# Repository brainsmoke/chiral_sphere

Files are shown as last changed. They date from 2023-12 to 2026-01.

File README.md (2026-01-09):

# Chiral Sphere

LED lamp based on a chiral spherical tiling consisting of 20 triangles and
12 Pentagons where the edge-length ratio triangle:pentagon is 2:1.

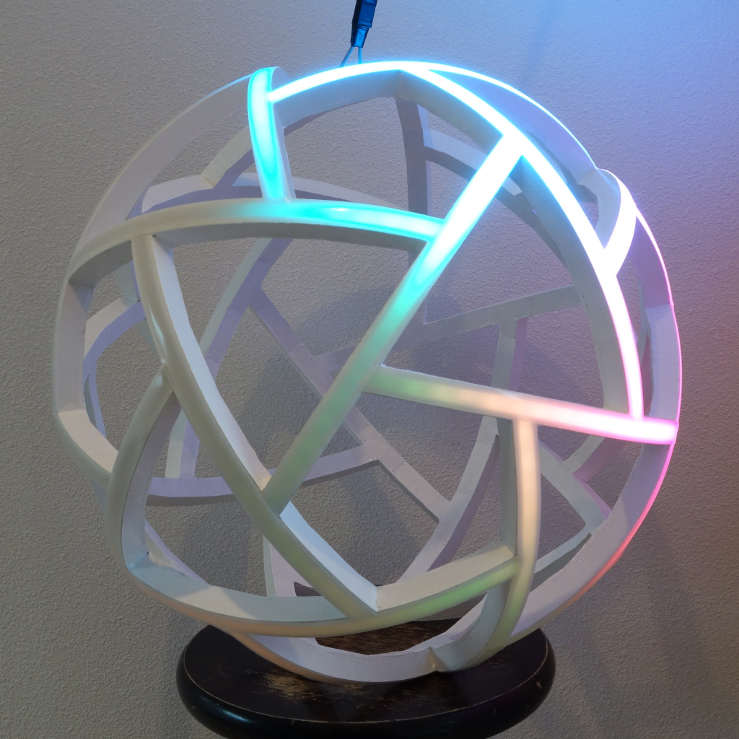
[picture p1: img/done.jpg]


[Video](https://mastodon.social/@brainsmoke/111589632039788005)

# Materials

* 2x 5m WS2812 LED strips, 60 LEDs/m spacing, 10mm wide, cut into 30 strips of 17
* +/- 11 meters flexible diffuser, 12mm wide
* [custom joint PCBs [kicad]](pcb/yjoint) [[svg]](pcb/yjoint/penta_joint.svg), [untested flexpcb alternative [kicad]](pcb/yjoint_v2) [[svg]](pcb/yjoint_v2/penta_joint_v2.svg)
* [LED driver board](https://github.com/brainsmoke/leddriver3d/tree/main/pcb/driver_slim_v1), [LED driver board v2](https://github.com/brainsmoke/leddriver3d/tree/main/pcb/driver_slim_v2)
* thin wire (for connecting the data lines)
* 2x ~30cm thick wire (to handle high currents near the power connector)
* 3mm plywood, 4x 600x400mm
* white paint
* wood glue

# Maths

* [Formula for the relation between corner arc and edge-length for regular N-gons on the unit sphere](https://github.com/brainsmoke/geometry/blob/main/spherical/ngonmath.png)
* [Calculation of the corner arc for this spherical tiling](https://github.com/brainsmoke/geometry/blob/main/spherical/2tri1penta.scad#L8-L34)
* [LED Locations & normals](https://github.com/brainsmoke/geometry/blob/main/scripts/led_locations.py)

# Cutting

Based on output from [one of my scripts](https://github.com/brainsmoke/geometry/blob/main/scripts/tube.py), but
with the outer panels removed so that the tubes become U-profiles and the sides modified so that they trace
a perfect sphere.

[Laser cut shapes](cut/v1/led.svg) (with some spares; apply appropriate kerf width compensation before cutting)

# Wiring

All strips are positioned such that data-in is above data-out, with one pentagon chosen
as top.  The strips are connected as five point-symmetrical led strips with 102 LEDs each
according to [this OpenSCAD model](doc/wiring.scad).

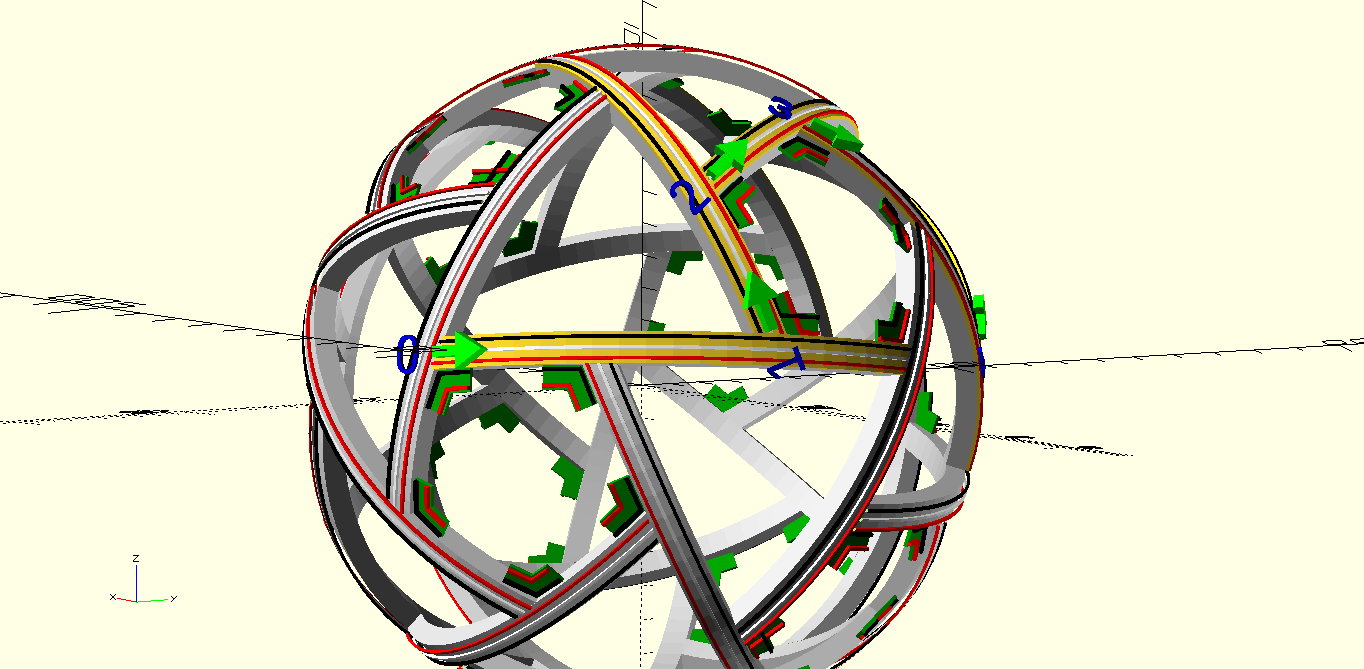
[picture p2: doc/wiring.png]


# LED Driver

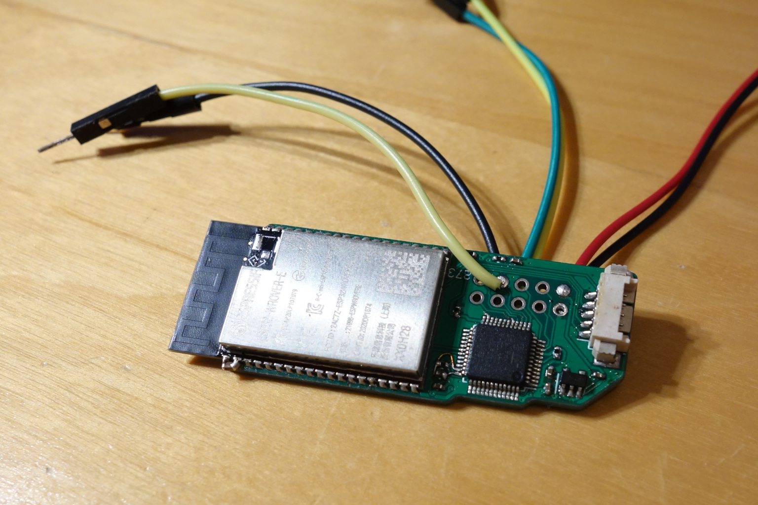
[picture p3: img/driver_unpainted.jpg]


[PCB](https://github.com/brainsmoke/leddriver3d/tree/main/pcb/driver_slim_v1)

# Software

* [Driver software repo](https://github.com/brainsmoke/leddriver3d)
* [STM32 Firmware: strip5.bin](https://github.com/brainsmoke/leddriver3d/tree/main/firmware/stm32/strip5)
* [LED positions](https://github.com/brainsmoke/leddriver3d/blob/main/firmware/esp32/models/chiral_tiling/leds.json)
* [conf/hardware.json](https://github.com/brainsmoke/leddriver3d/blob/main/firmware/esp32/conf/chiral_tiling/hardware.json)

# More pictures

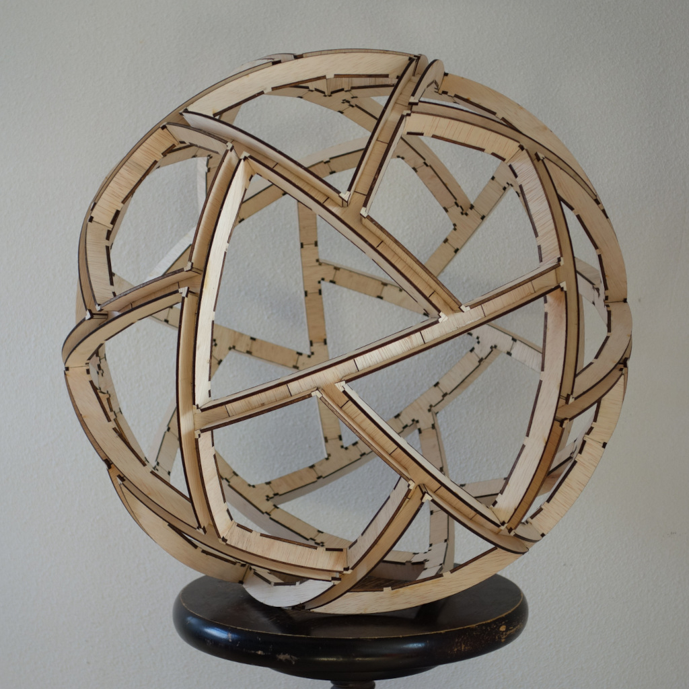
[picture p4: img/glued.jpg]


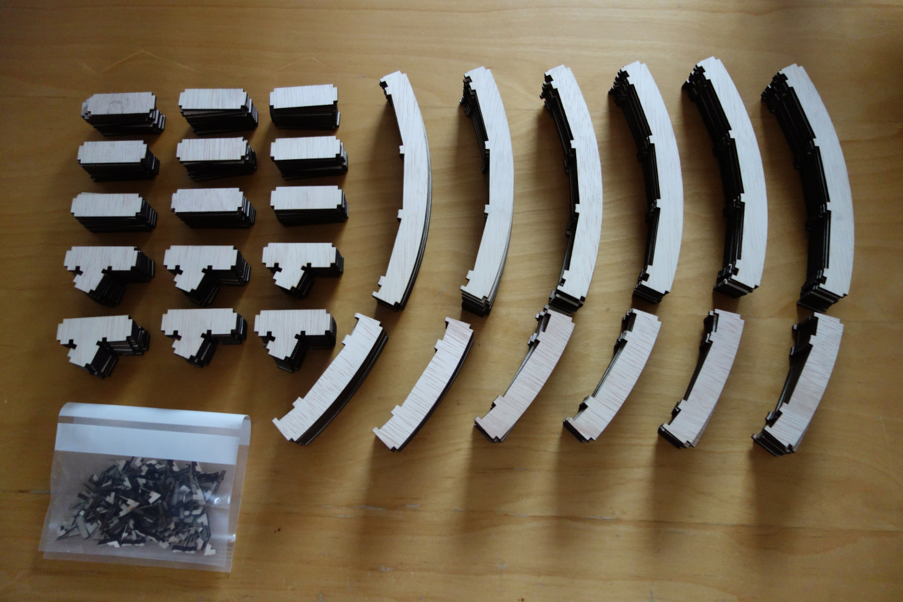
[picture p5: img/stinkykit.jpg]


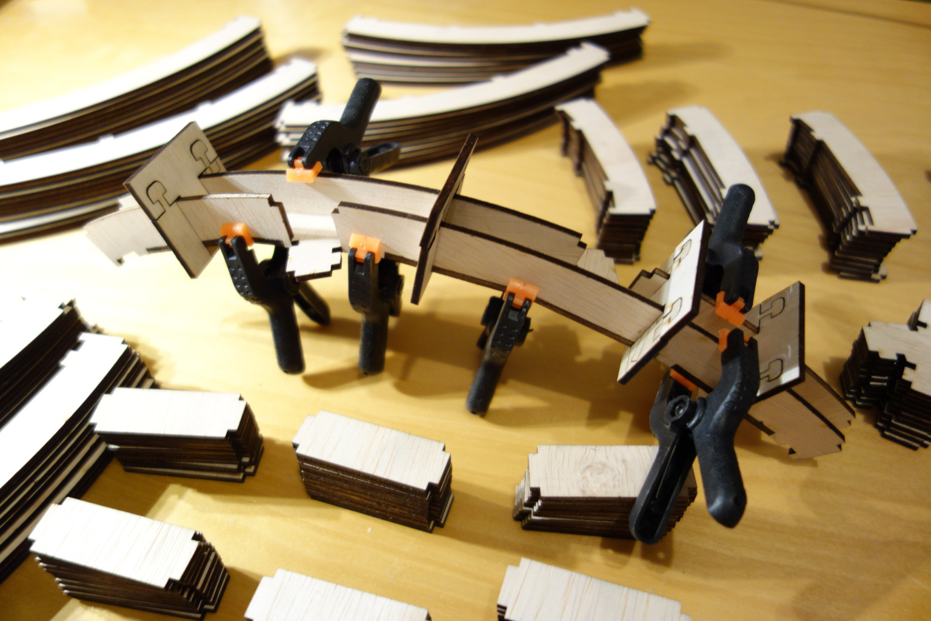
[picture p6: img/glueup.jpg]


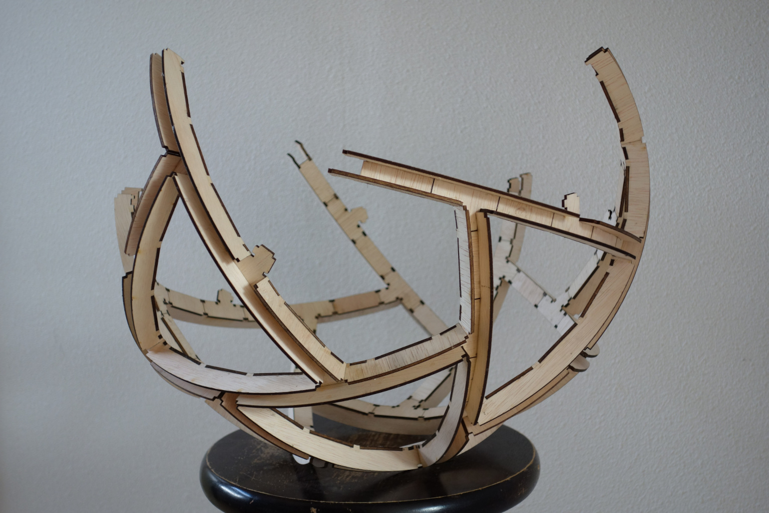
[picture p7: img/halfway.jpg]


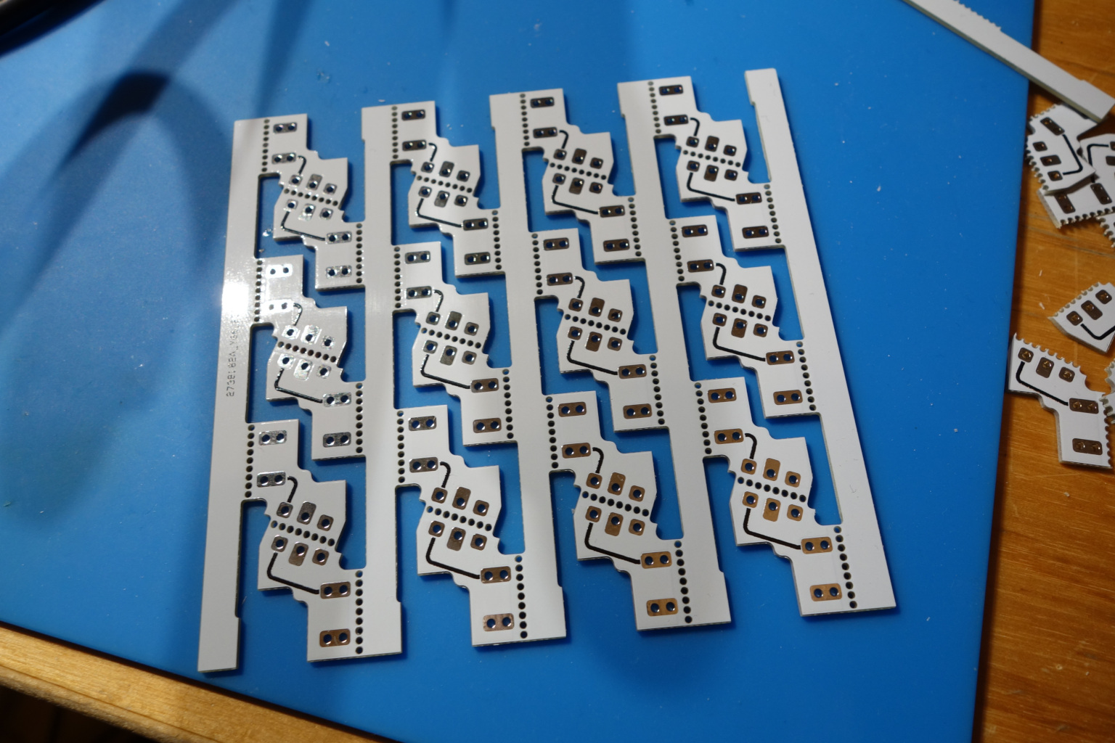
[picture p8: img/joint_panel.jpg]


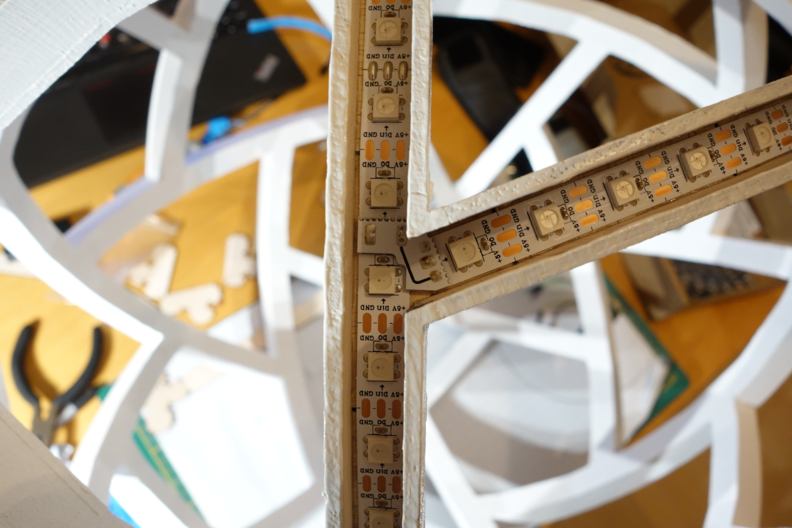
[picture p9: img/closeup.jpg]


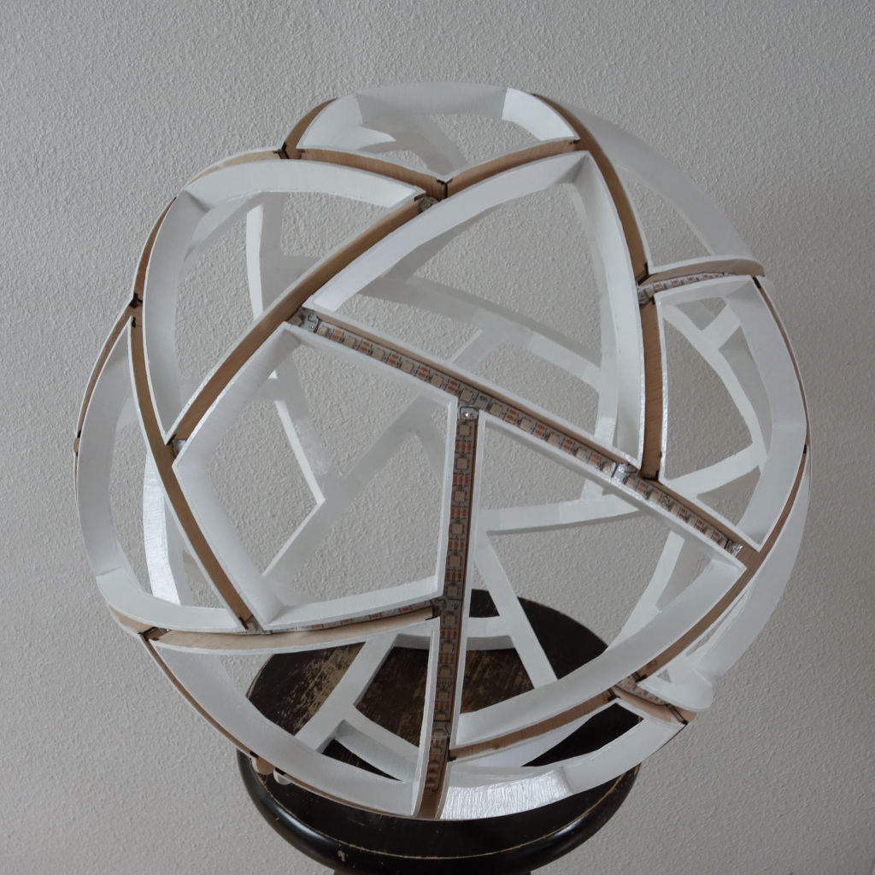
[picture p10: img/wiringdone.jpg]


Add extra capacity to the strip which needs to handle the most Amps.
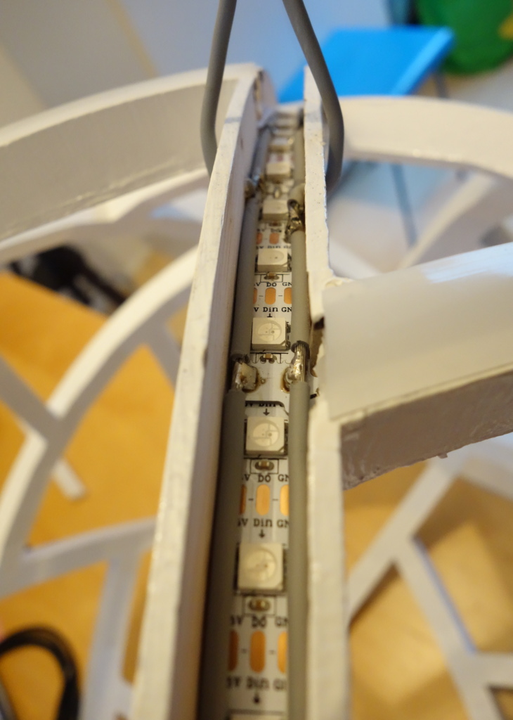
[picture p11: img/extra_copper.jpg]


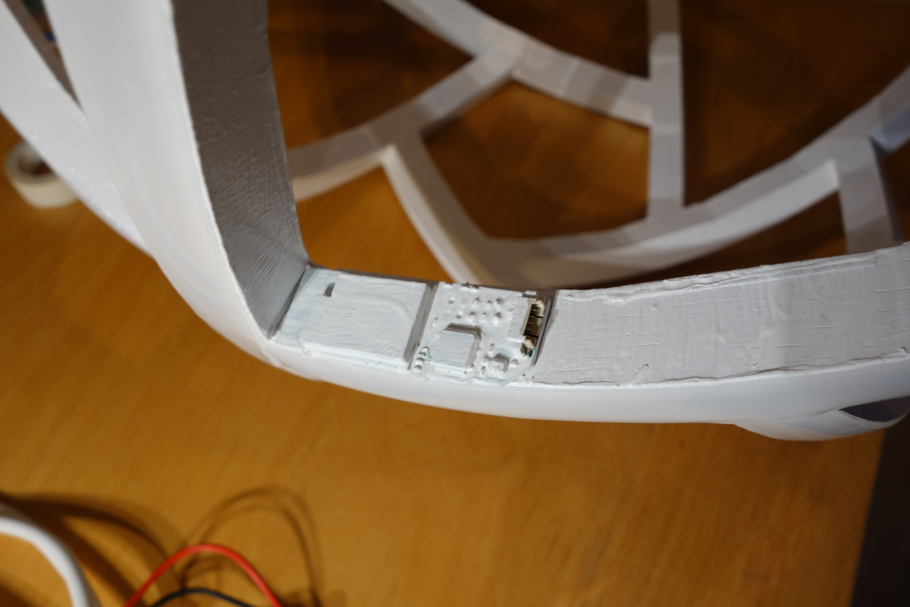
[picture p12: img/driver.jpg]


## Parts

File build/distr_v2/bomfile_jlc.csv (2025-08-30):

Comment | Designator | Footprint | JLCPCB Part #
1uF | C1,C2,C3,C4,C5 | Capacitor_SMD:C_0603_1608Metric | C15849
BSMD1812-200-30V | F1 | Fuse:Fuse_1812_4532Metric | C960026
0Ohm,0ohm | R1,R4 | Resistor_SMD:R_0603_1608Metric | C21189
330R | R2,R3,R5 | Resistor_SMD:R_0603_1608Metric | C23138
STM32F030F4Px | U2 | Package_SO:TSSOP-20_4.4x6.5mm_P0.65mm | C89040
AP2112K-3.3 | U3 | Package_TO_SOT_SMD:SOT-23-5 | C51118
74LVC2G17 | U4 | Package_TO_SOT_SMD:SOT-23-6_Handsoldering | C10429
TLP2361 | U5 | Package_SO:SO-5_4.4x3.6mm_P1.27mm | C107626

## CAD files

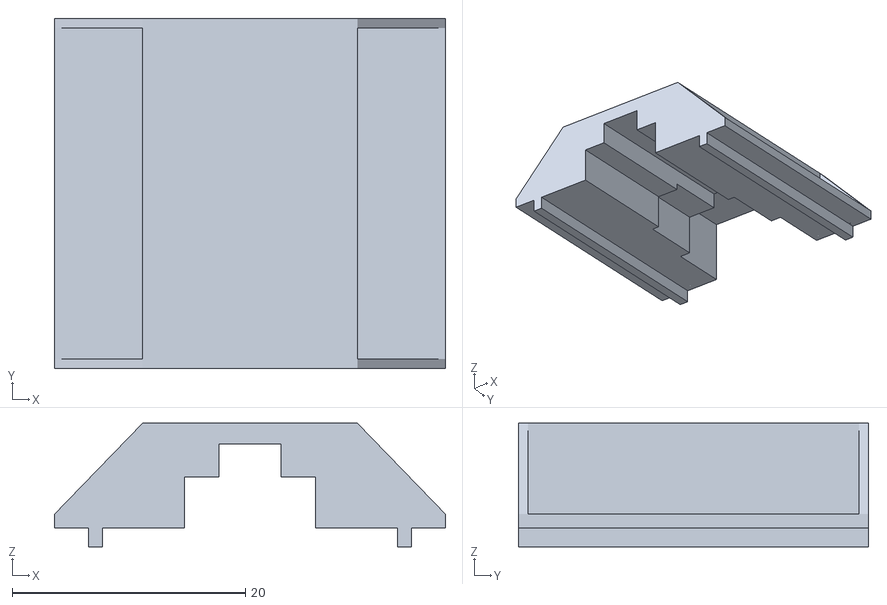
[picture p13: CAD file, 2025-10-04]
scad/assembly_tool.stl
33.5 x 30.0 x 10.6

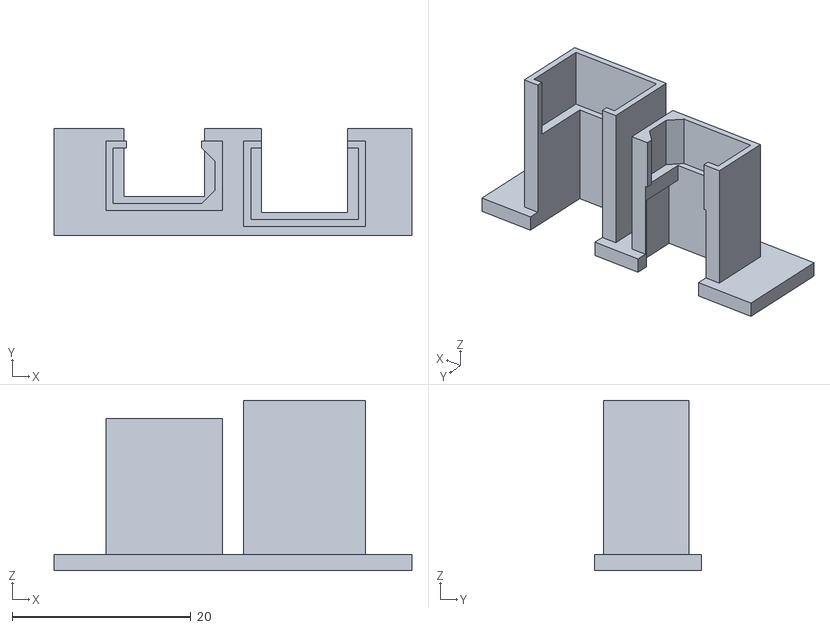
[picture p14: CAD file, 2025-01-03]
scad/assembly_tool_big.stl
40.0 x 12.0 x 19.0

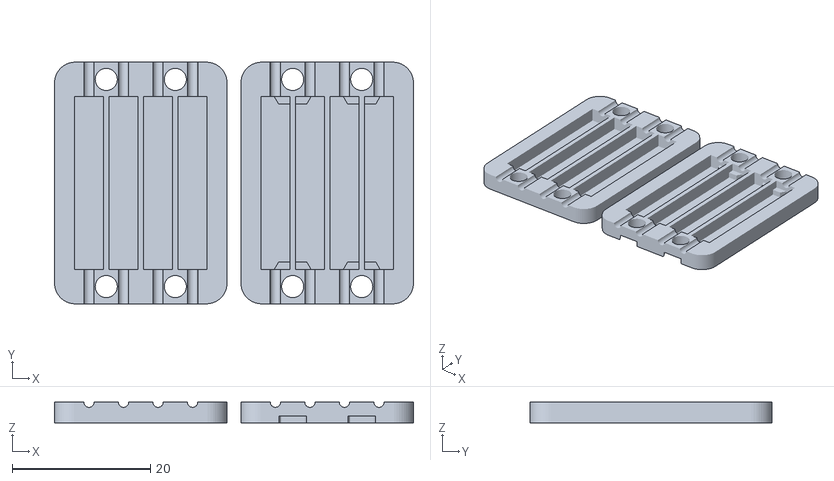
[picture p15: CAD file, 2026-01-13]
scad/clamp.stl
52.0 x 35.0 x 3.00

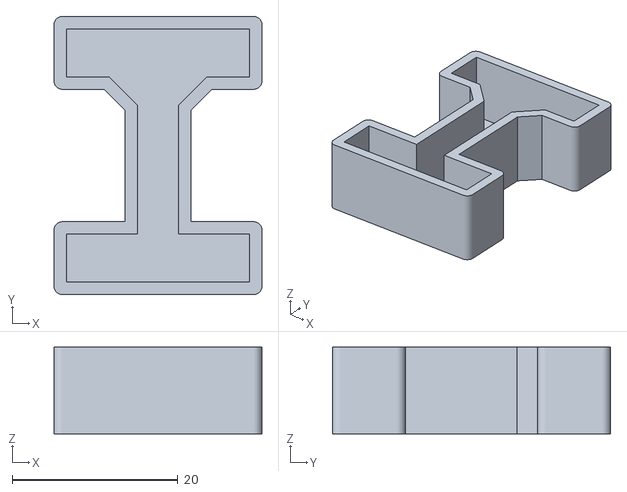
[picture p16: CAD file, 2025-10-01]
scad/power_insert.stl
25.1 x 33.6 x 10.5

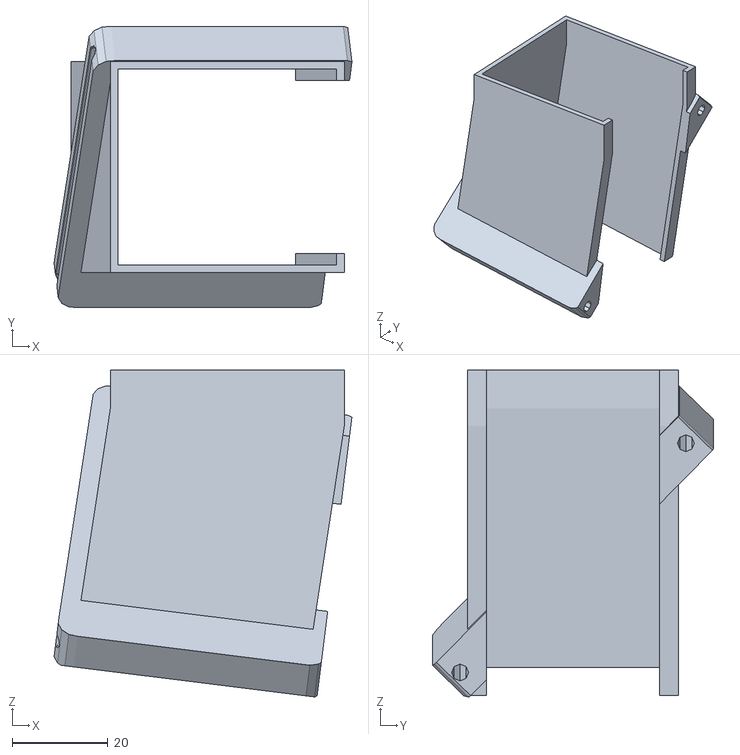
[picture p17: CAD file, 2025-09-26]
scad/wire_guide_big.stl
62.2 x 58.7 x 68.2

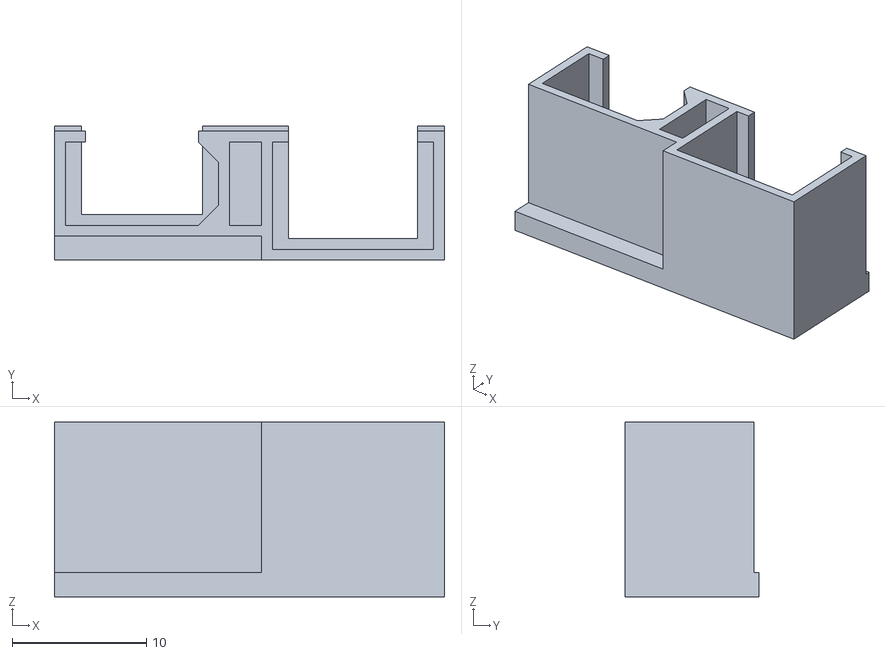
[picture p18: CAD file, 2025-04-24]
scad/insert.stl
29.0 x 10.0 x 13.0

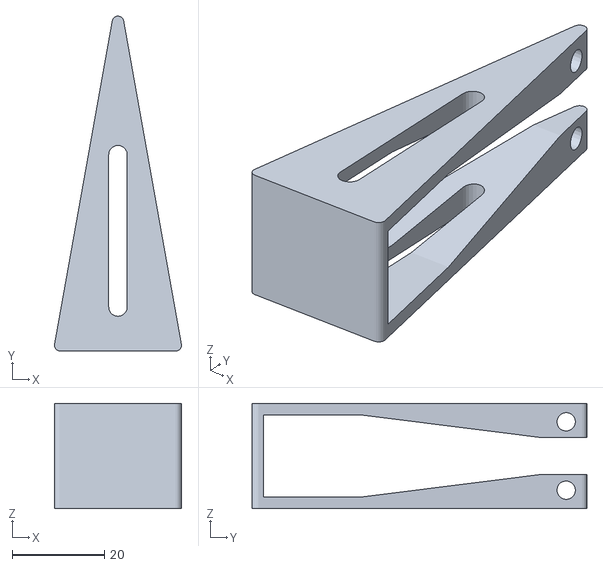
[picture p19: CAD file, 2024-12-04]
scad/hanger_v2.stl
27.5 x 72.5 x 22.8

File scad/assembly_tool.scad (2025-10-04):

e=.001;

jig_h=9;
tunnel_w=33.5;
m=.15;
plug_w=12.8;
plug_h=5.2;
plug_d=7.6;
clamp_w=5;
clamp_h=2;
pcb_w=25;
pcb_h=1.6;
front_d=15;
border=1.2;
push_border=.8;

jig_d=30;

conn_w=15.6;
conn_clearance_h=8;
conn_d=10;

module midx_cube(pos)
{
	translate([-pos.x/2, 0, 0])
	cube(pos);
}

module hat()
{
difference()
{
midx_cube([tunnel_w, jig_d, jig_h]);
for (x=[-1,1])
{
	translate([x*19.2,-e,border])
		midx_cube([20,jig_d+1,20]);

}
}

difference()
{
translate([0,0,-pcb_h])
midx_cube([pcb_w+2*m+border*2, jig_d, pcb_h+e]);
translate([0,-e,-pcb_h-e])
midx_cube([pcb_w+2*m, jig_d+2*e, pcb_h+2*e]);

}

}




difference()
{
union()
{
hat();
intersection()
{
hull()hat();
union()
{
translate([0,-e,-e])
midx_cube([tunnel_w+1, push_border+e, jig_h+1]);
translate([0,jig_d-push_border,-e])
midx_cube([tunnel_w+1, push_border+e, jig_h+1]);

}
}
}
translate([0,-e,-e])
{
midx_cube([plug_w-2*push_border,front_d+e*2,plug_h+e-push_border]);
midx_cube([clamp_w+2*m,front_d+plug_d+2*e,clamp_h+plug_h+e]);
}

translate([0, front_d,-e])
{
midx_cube([plug_w+2*m,plug_d+e,plug_h+e]);
}

translate([0, front_d+plug_d,-e])
midx_cube([conn_w+3*m, conn_d, conn_clearance_h+e]);

}

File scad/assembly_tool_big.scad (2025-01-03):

e=.001;
xt30_w=11.4;
xt30_h=6.2;
b=.8;
n=1.2;
xt30_n=1.5;

rj45_w=12;
rj45_h=8;


module keepout(w, h, b, n)
{
translate([0,0,12])
linear_extrude(8+e)
	translate([b,b])
	polygon([[0,0], [w,0], [w,h], [w-n,h], [w-n,h+b+e], [n,h+b+e], [n, h], [0,h]]);
}

module xt_keepout(w, h, b, n, ch)
{
translate([0,0,11])
linear_extrude(8+e)
	translate([b,b])
	polygon([[0,0], [w-ch,0], [w, ch], [w,h-ch], [w-n,h], [w-n,h+b+e], [n,h+b+e], [n, h], [0,h]]);
}


module xt_clam()
{
{
	difference()
	{
linear_extrude(17)
		square([xt30_w+b*2,xt30_h+b*2]);
		xt_keepout(xt30_w, xt30_h, b, xt30_n, xt30_n);
	}
}
}

module rj45_clam()
{
{
	difference()
	{
linear_extrude(19)
		square([rj45_w+b*2,rj45_h+b*2]);
		keepout(rj45_w, rj45_h, b, n);
	}
}
}

//cube([33,10,9+e]);
//translate([0,0,9])

difference()
{
union(){
translate([1.8,rj45_h-xt30_h])
xt_clam();
translate([17.2,0])
rj45_clam();
translate([-4,-1,0])
cube([40,12,1.8]);
}
union(){
translate([1.8+b+n,rj45_h-xt30_h+b*2,-e])
cube([xt30_w-2*n,12,e*2+11]);
translate([1.9+b,rj45_h-xt30_h+b*2,-e])
cube([xt30_w,6,9]);

translate([17.2+b+n,b*2,-e])
cube([rj45_w-2*n,12,e*2+12]);
}
}

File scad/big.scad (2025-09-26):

r = 568.9023130792767;
w = 40.0;
subdivisions = 3;
thickness = 3.0;
top_space = 19.0;
bottom_space = 15.0;
h = 3*thickness+top_space+bottom_space;




module subdiv_arc(a, n)
{
    if (n > 0)
        rotate([0,0,a])
        {
            children();
            subdiv_arc(a,n-1)children();
        }
}

module joint()
{
    translate([r-thickness,0,0])
    rotate([0,90,0])
    rotate([0,0,90-A])
    top_joint();

    translate([r-2*thickness-top_space,0,0])
    rotate([0,90,0])
    rotate([0,0,90-A])
    mid_joint();

    translate([r-h+thickness,0,0])
    rotate([0,-90,0])
    rotate([0,0,A-90])
    bottom_joint();
}

module subdiv()
{
    translate([r-thickness,0,0])
    rotate([0,90,0])
    rotate([0,0,90])
    top_div();

    translate([r-2*thickness-top_space,0,0])
    rotate([0,90,0])
    rotate([0,0,90])
    mid_div();

    translate([r-h+thickness,0,0])
    rotate([0,-90,0])
    rotate([0,0,-90])
    bottom_div();
}

module big_side()
{
    translate([r-h,(w/2)*(cos_A+1)/sin(A),-w/2])
    rotate([-A,0,0])
    rotate([0,0,90])
    translate([0,0,-thickness])
    big_arc();
}

module small_side()
{
    translate([r-h,-(w/2)*(cos_A-1)/sin(A),w/2])
    rotate([0,0,90])
    translate([0,0,-thickness])
    small_arc();
}

module arc()
{
    joint();

    subdiv_arc(alpha/2/subdivisions, subdivisions-1)subdiv();

    rotate([-A,0,0])
    subdiv_arc(alpha/2/subdivisions, subdivisions-1)subdiv();

    big_side();
    small_side();
}




/*
* alpha = 2*beta
* cos (alpha) = 1 / (1-cos(A)) - 1
* cos (beta)  = (phi + 1) / (1+cos(A)) - 1
*
* let x = cos(A)
*
* 1 / (1-x) -1 = 2 * ( (phi + 1)/(1+x) - 1 )^2 - 1
*
* x^3+(-2*phi-1/2)x^2+(3*phi+2)x + (-phi-1/2) = 0
*/

phi=(1+sqrt(5))/2;
cuberoot=pow(118*phi+85+6*sqrt(1173*phi+729), 1/3);
cos_A=(1/6)*(4*phi+1) +
      (1/6)*(12*phi+7)/cuberoot -
      (1/6)*cuberoot;

A=acos(cos_A);

cos_alpha=1/(1-cos_A)-1;
alpha=acos(cos_alpha);

module step_x()
{
   rotate([0,0,alpha/2])rotate([A,0,0])
   children();
}

module step_y()
{
   rotate([0,0,3*alpha/2])rotate([180,0,0])
   children();
}

module penta()
{
   children();
   step_x(){
	   children();
	   step_x(){
		   children();
		   step_x(){
			   children();
			   step_x(){
				   children();
			   }
		   }
	   }
   }
}

module extend()
{
   children();
   step_y()step_x()step_x()step_x()
   {
	   penta()children();
	   step_y(){
		   penta()children();
		   step_x()step_x()step_y()children();
	   }
   }
}

module top_joint ()
{
	linear_extrude(thickness) polygon([[-43.11421341813179, -17.0],[-43.11421341813178, 17.0],[-40.11421341813178, 17.0],[-40.11421341813178, 20.0],[-16.41232297632699, 20.0],[-16.41232297632699, 17.0],[-13.41232297632699, 17.0],[-13.412322976326989, 20.0],[-10.636835166895432, 18.861286945847716],[-9.498122112743149, 21.636774755279273],[-12.273609922174705, 22.775487809431556],[-3.2770592374512546, 44.70359047000207],[-0.5015714280196981, 43.564877415849786],[0.6371416261325857, 46.34036522528134],[32.09267013302355, 33.43495061155545],[30.953957078871273, 30.6594628021239],[33.72944488830283, 29.520749747971617],[30.96203304920517, 22.775487809431556],[28.186545239773615, 23.91420086358384],[27.04783218562133, 21.138713054152284],[29.823319995052888, 20.0],[29.823319995052888, 17.0],[32.823319995052884, 17.0],[32.823319995052884, 20.0],[40.11421341813178, 20.0],[40.11421341813178, 17.0],[43.11421341813179, 17.0],[43.11421341813178, -17.0],[40.11421341813178, -17.0],[40.11421341813178, -20.0],[-40.11421341813178, -20.0],[-40.11421341813178, -17.0]],[[0,1,2,3,4,5,6,7,8,9,10,11,12,13,14,15,16,17,18,19,20,21,22,23,24,25,26,27,28,29,30,31]]);
}
module mid_joint ()
{
	linear_extrude(thickness) polygon([[-41.43810665327744, -17.0],[-41.43810665327744, 17.0],[-36.93810665327744, 17.0],[-36.93810665327744, 20.0],[-32.43810665327744, 20.0],[-32.43810665327744, 17.0],[-22.41232297632699, 17.0],[-22.41232297632699, 20.0],[-17.91232297632699, 20.0],[-17.91232297632699, 17.0],[-13.41232297632699, 17.0],[-13.412322976326989, 20.0],[-10.636835166895432, 18.861286945847716],[-8.928765585667007, 23.024518659995053],[-11.704253395098563, 24.163231714147337],[-9.99618381387014, 28.32646342829467],[-7.220696004438583, 27.187750374142386],[-3.415199087421798, 36.463230499267006],[-6.190686896853355, 37.60194355341929],[-4.48261731562493, 41.76517526756662],[-1.7071295061933736, 40.626462213414335],[0.0009400750350510023, 44.78969392756167],[31.45646858192602, 31.88427931383579],[28.755901766849757, 25.30194476829962],[31.531389576281313, 24.163231714147337],[29.823319995052888, 20.0],[34.323319995052884, 20.0],[34.323319995052884, 17.0],[41.43810665327744, 17.0],[41.43810665327744, -17.0],[36.93810665327744, -17.0],[36.93810665327744, -20.0],[32.43810665327744, -20.0],[32.43810665327744, -17.0],[-32.43810665327744, -17.0],[-32.43810665327744, -20.0],[-36.93810665327744, -20.0],[-36.93810665327744, -17.0]],[[0,1,2,3,4,5,6,7,8,9,10,11,12,13,14,15,16,17,18,19,20,21,22,23,24,25,26,27,28,29,30,31,32,33,34,35,36,37]]);
}
module bottom_joint ()
{
	linear_extrude(thickness) polygon([[37.06674657294206, -17.0],[37.06674657294206, -20.0],[-37.06674657294206, -20.0],[-37.06674657294206, -17.0],[-40.06674657294206, -17.0],[-40.06674657294206, 17.0],[-37.06674657294206, 17.0],[-37.06674657294206, 20.0],[-32.823319995052884, 20.0],[-32.823319995052884, 17.0],[-29.823319995052888, 17.0],[-29.823319995052888, 20.0],[-27.04783218562133, 21.138713054152284],[-28.186545239773615, 23.91420086358384],[-30.96203304920517, 22.775487809431556],[-32.57271479539822, 26.701347388481313],[-29.797226985966663, 27.840060442633597],[-30.935940040118947, 30.615548252065153],[0.5195884667720212, 43.520962865791034],[1.6583015209243044, 40.745475056359474],[4.433789330355861, 41.88418811051176],[12.273609922174705, 22.775487809431556],[9.498122112743149, 21.636774755279273],[10.636835166895432, 18.861286945847716],[13.412322976326989, 20.0],[13.41232297632699, 17.0],[16.41232297632699, 17.0],[16.41232297632699, 20.0],[37.06674657294206, 20.0],[37.06674657294206, 17.0],[40.06674657294206, 17.0],[40.06674657294206, -17.0]],[[0,1,2,3,4,5,6,7,8,9,10,11,12,13,14,15,16,17,18,19,20,21,22,23,24,25,26,27,28,29,30,31]]);
}
module top_div ()
{
	linear_extrude(thickness) polygon([[-43.11421341813179, -17.0],[-43.11421341813178, 17.0],[-40.11421341813178, 17.0],[-40.11421341813178, 20.0],[40.11421341813178, 20.0],[40.11421341813178, 17.0],[43.11421341813179, 17.0],[43.11421341813178, -17.0],[40.11421341813178, -17.0],[40.11421341813178, -20.0],[-40.11421341813178, -20.0],[-40.11421341813178, -17.0]],[[0,1,2,3,4,5,6,7,8,9,10,11]]);
}
module mid_div ()
{
	linear_extrude(thickness) polygon([[-41.43810665327744, -17.0],[-41.43810665327744, 17.0],[-36.93810665327744, 17.0],[-36.93810665327744, 20.0],[-32.43810665327744, 20.0],[-32.43810665327744, 17.0],[32.43810665327744, 17.0],[32.43810665327744, 20.0],[36.93810665327744, 20.0],[36.93810665327744, 17.0],[41.43810665327744, 17.0],[41.43810665327744, -17.0],[36.93810665327744, -17.0],[36.93810665327744, -20.0],[32.43810665327744, -20.0],[32.43810665327744, -17.0],[-32.43810665327744, -17.0],[-32.43810665327744, -20.0],[-36.93810665327744, -20.0],[-36.93810665327744, -17.0]],[[0,1,2,3,4,5,6,7,8,9,10,11,12,13,14,15,16,17,18,19]]);
}
module bottom_div ()
{
	linear_extrude(thickness) polygon([[37.06674657294206, -17.0],[37.06674657294206, -20.0],[-37.06674657294206, -20.0],[-37.06674657294206, -17.0],[-40.06674657294206, -17.0],[-40.06674657294206, 17.0],[-37.06674657294206, 17.0],[-37.06674657294206, 20.0],[37.06674657294206, 20.0],[37.06674657294206, 17.0],[40.06674657294206, 17.0],[40.06674657294206, -17.0]],[[0,1,2,3,4,5,6,7,8,9,10,11]]);
}
module big_arc ()
{
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

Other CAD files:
scad/unclip_tool.stl
scad/big_solid.scad
cut/tri/tri.scad
cut/v1/led.scad
doc/wiring.scad
scad/clamp.scad
scad/hanger_v2.scad
scad/insert.scad
scad/power_insert.scad
scad/unclip_tool.scad
scad/wire_guide_big.scad

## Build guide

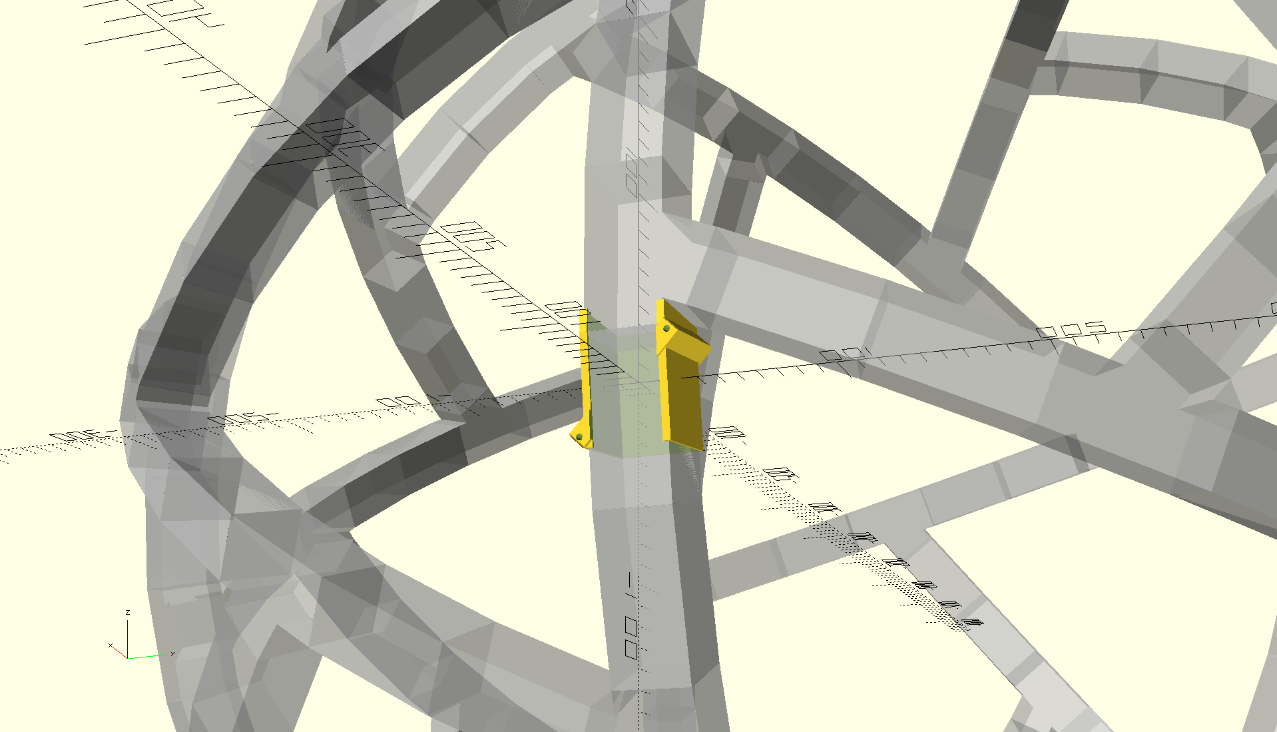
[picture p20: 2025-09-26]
scad/wire_guide_big.png

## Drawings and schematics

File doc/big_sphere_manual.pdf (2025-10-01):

## Ring 0:

## Big sphere

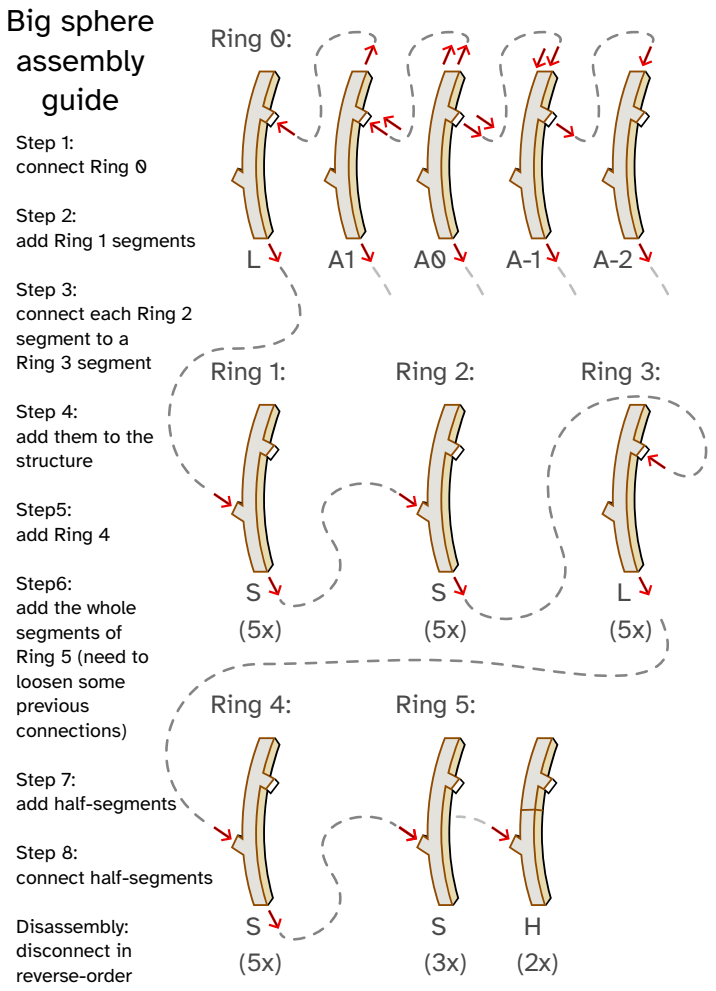
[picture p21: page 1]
Ring 1:; Ring 2:; Ring 3:; Ring 4:; Ring 5:; assembly guide; Step 1: connect Ring 0; Step5: add Ring 4; Disassembly: disconnect in reverse-order

Step 2:
add Ring 1 segments

Step 3:
connect each Ring 2
segment to a
Ring 3 segment

Step 4:
add them to the
structure

Step6:
add the whole
segments of
Ring 5 (need to
loosen some
previous
connections)

Step 7:
add half-segments

Step 8:
connect half-segments

A1

L⁶x A-2 | A0

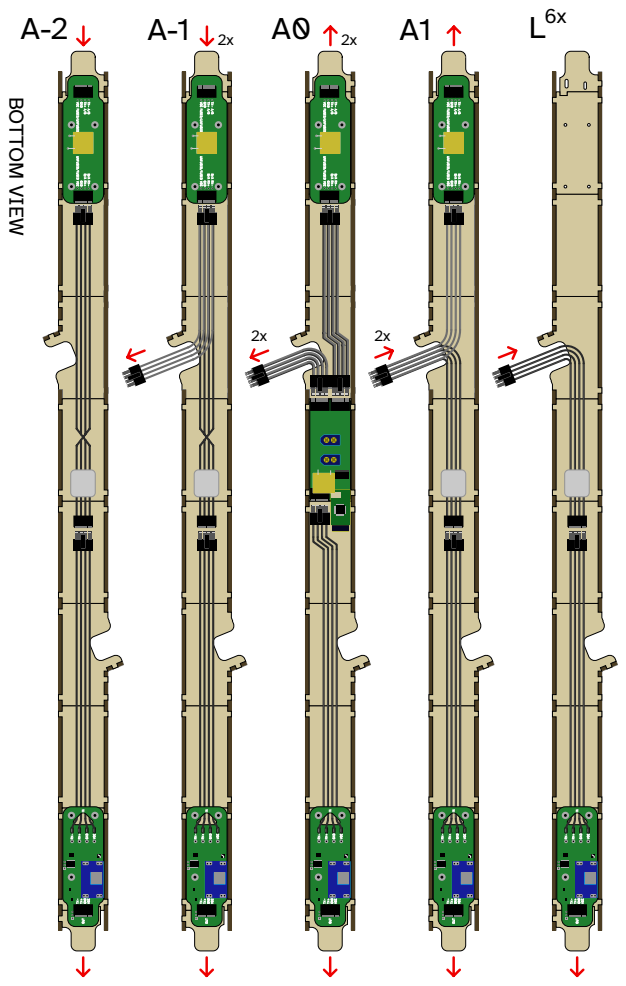
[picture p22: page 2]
BOTTOM VIEW

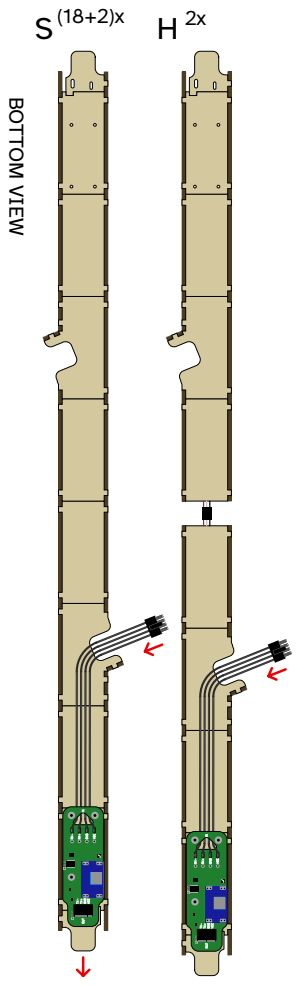
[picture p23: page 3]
BOTTOM VIEW

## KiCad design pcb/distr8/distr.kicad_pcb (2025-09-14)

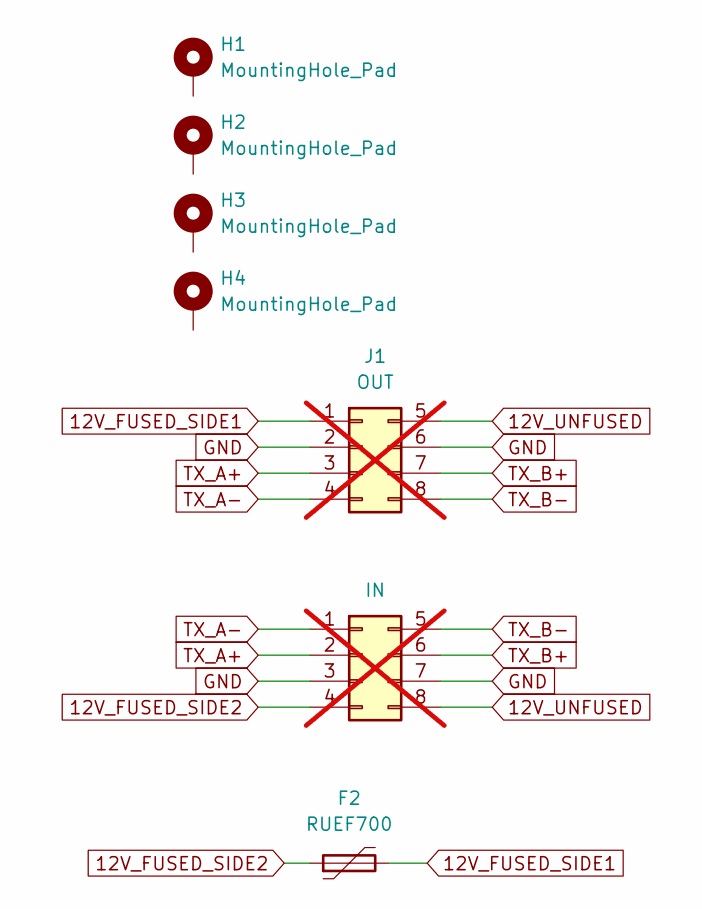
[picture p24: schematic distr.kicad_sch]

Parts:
F2: RUEF700; Fuse_Littlefuse_RUEF
H1, H2, H3, H4: MountingHole_Pad
J1: OUT; Molex_Micro-Fit_3.0_43045-0800_2x04_P3.00mm_Horizontal; not fitted
J2: IN; Molex_Micro-Fit_3.0_43045-0800_2x04_P3.00mm_Horizontal; not fitted

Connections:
12V_FUSED_SIDE1: F2.2, J1.1
12V_FUSED_SIDE2: F2.1, J2.4
12V_UNFUSED: J1.5, J2.8
GND: J1.2, J1.6, J2.3, J2.7
TX_A+: J1.3, J2.2
TX_A-: J1.4, J2.1
TX_B+: J1.7, J2.6
TX_B-: J1.8, J2.5

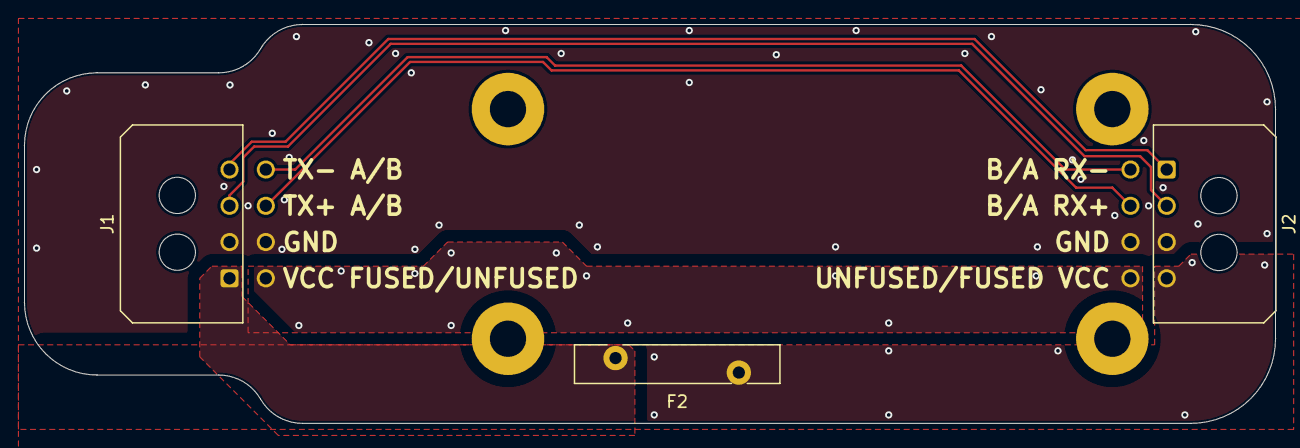
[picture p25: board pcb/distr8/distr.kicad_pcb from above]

Board: 2 copper layers, 103.5 x 33.0 mm, 7 parts (0 on the bottom side), 8 nets.

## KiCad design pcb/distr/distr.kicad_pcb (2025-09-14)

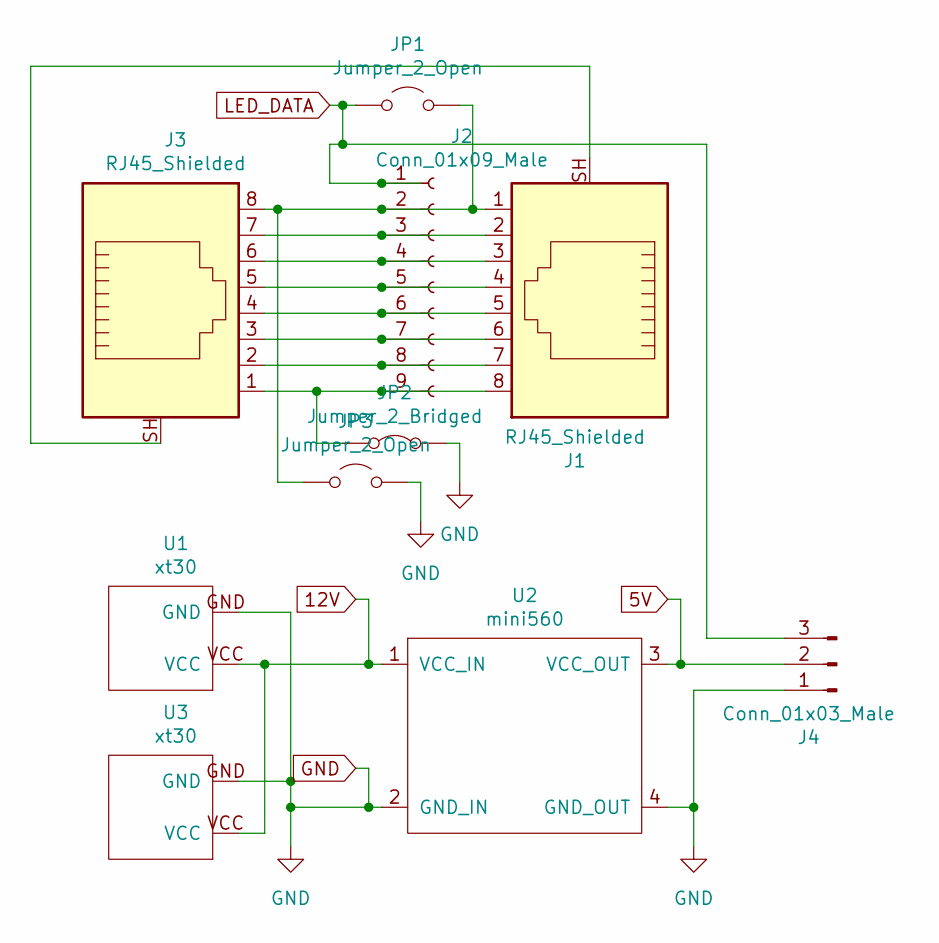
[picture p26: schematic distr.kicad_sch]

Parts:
J1, J3: RJ45_Shielded; HC-RJ45-055-7
J2: Conn_01x09_Male; PinHeader_1x09_P2.54mm_Vertical
J4: Conn_01x03_Male; PinHeader_1x03_P2.54mm_Vertical
JP1: Jumper_2_Open; SolderJumper-2_P1.3mm_Open_TrianglePad1.0x1.5mm
JP2: Jumper_2_Bridged; SolderJumper-2_P1.3mm_Bridged_RoundedPad1.0x1.5mm
JP3: Jumper_2_Open; SolderJumper-2_P1.3mm_Open_RoundedPad1.0x1.5mm
U1: xt30; xt30-PW-F_banana
U2: mini560
U3: xt30; xt30-PW-M_banana

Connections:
5V: J4.2, U2.3 (VCC_OUT)
12V: U1.VCC, U2.1 (VCC_IN), U3.VCC
GND: J4.1, JP2.2 (B), JP3.2 (B), U1.GND, U2.2 (GND_IN), U2.4 (GND_OUT), U3.GND
LED_DATA: J2.1, J4.3, JP1.1 (A)
unnamed: J1.SH, J3.SH
unnamed: J1.1, J2.2, J3.8, JP1.2 (B), JP3.1 (A)
unnamed: J1.2, J2.3, J3.7
unnamed: J1.3, J2.4, J3.6
unnamed: J1.4, J2.5, J3.5
unnamed: J1.5, J2.6, J3.4
unnamed: J1.6, J2.7, J3.3
unnamed: J1.7, J2.8, J3.2
unnamed: J1.8, J2.9, J3.1, JP2.1 (A)

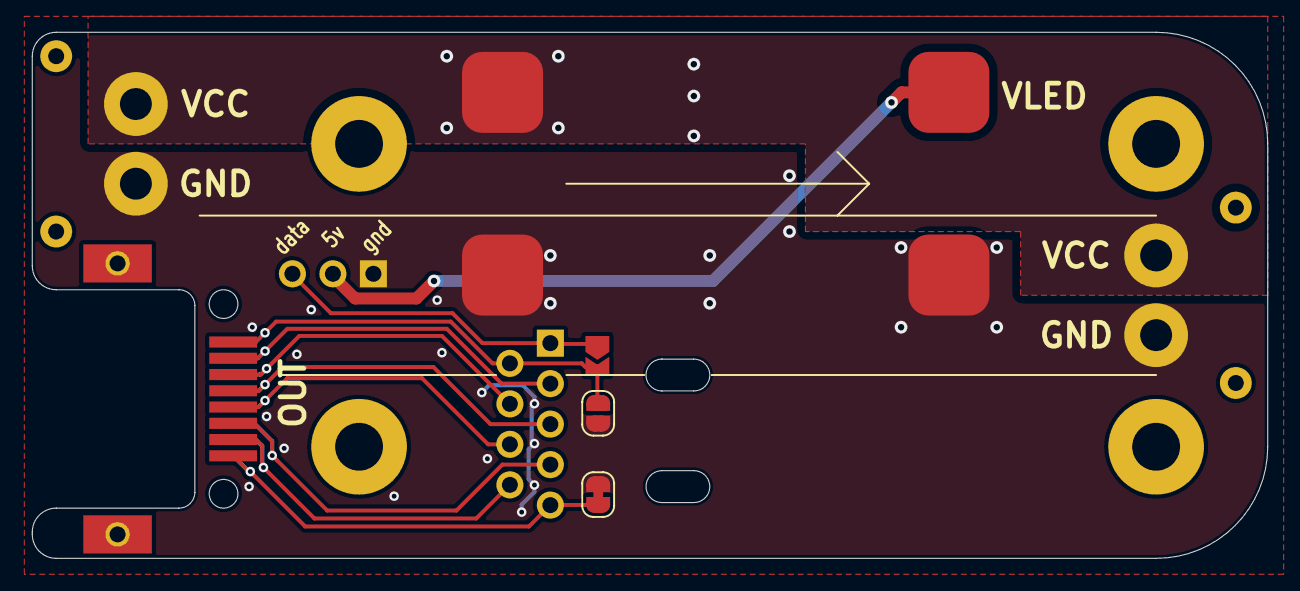
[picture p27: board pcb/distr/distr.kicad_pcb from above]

Board: 2 copper layers, 77.5 x 33.0 mm, 10 parts (1 on the bottom side), 13 nets.

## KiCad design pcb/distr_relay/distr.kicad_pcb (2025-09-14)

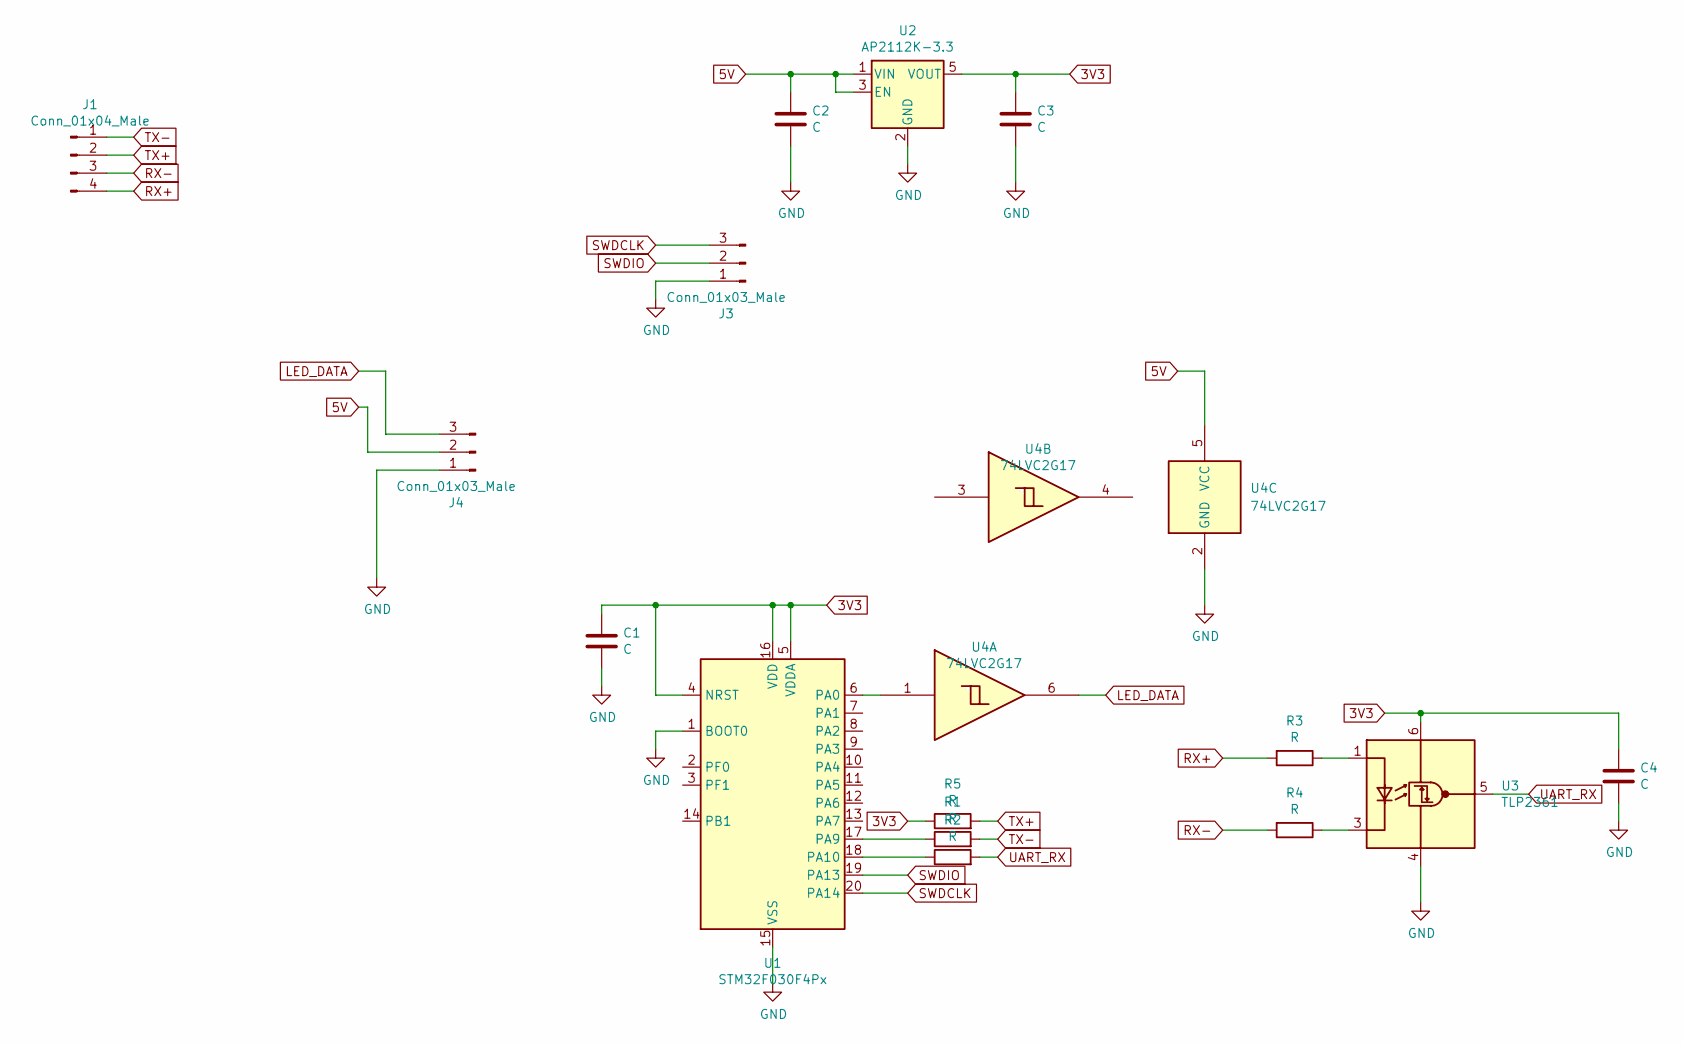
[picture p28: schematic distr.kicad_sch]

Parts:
C1, C2, C3, C4: C; C_0603_1608Metric
J1: Conn_01x04_Male; PinHeader_1x04_P2.54mm_Vertical
J3, J4: Conn_01x03_Male; PinHeader_1x03_P2.54mm_Vertical
R1, R2, R3, R4, R5: R; R_0603_1608Metric
U1: STM32F030F4Px; TSSOP-20_4.4x6.5mm_P0.65mm
U2: AP2112K-3.3; SOT-23-5
U3: TLP2361; SO-6_4.4x3.6mm_P1.27mm
U4: 74LVC2G17

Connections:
3V3: C1.1, C3.1, C4.1, R5.1, U1.4 (NRST), U1.5 (VDDA), U1.16 (VDD), U2.5 (VOUT), U3.6 (VDD)
5V: C2.1, J4.2, U2.1 (VIN), U2.3 (EN), U4.5 (VCC)
GND: C1.2, C2.2, C3.2, C4.2, J3.1, J4.1, U1.1 (BOOT0), U1.15 (VSS), U2.2 (GND), U3.4 (GND), U4.2 (GND)
LED_DATA: J4.3, U4.6
unnamed: U1.6 (PA0), U4.1
unnamed: R1.1, U1.17 (PA9)
unnamed: R2.1, U1.18 (PA10)
unnamed: R3.1, U3.1 (A)
unnamed: R4.1, U3.3 (K)
RX+: J1.4, R3.2
RX-: J1.3, R4.2
SWDCLK: J3.3, U1.20 (PA14)
SWDIO: J3.2, U1.19 (PA13)
TX+: J1.2, R5.2
TX-: J1.1, R1.2
UART_RX: R2.2, U3.5 (VO)

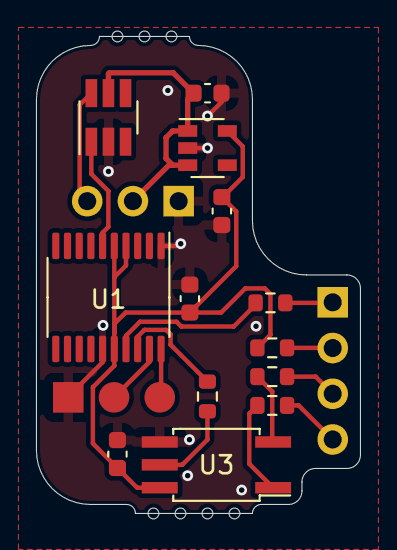
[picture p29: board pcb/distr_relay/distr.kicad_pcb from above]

Board: 2 copper layers, 18.0 x 26.5 mm, 16 parts (0 on the bottom side), 16 nets.

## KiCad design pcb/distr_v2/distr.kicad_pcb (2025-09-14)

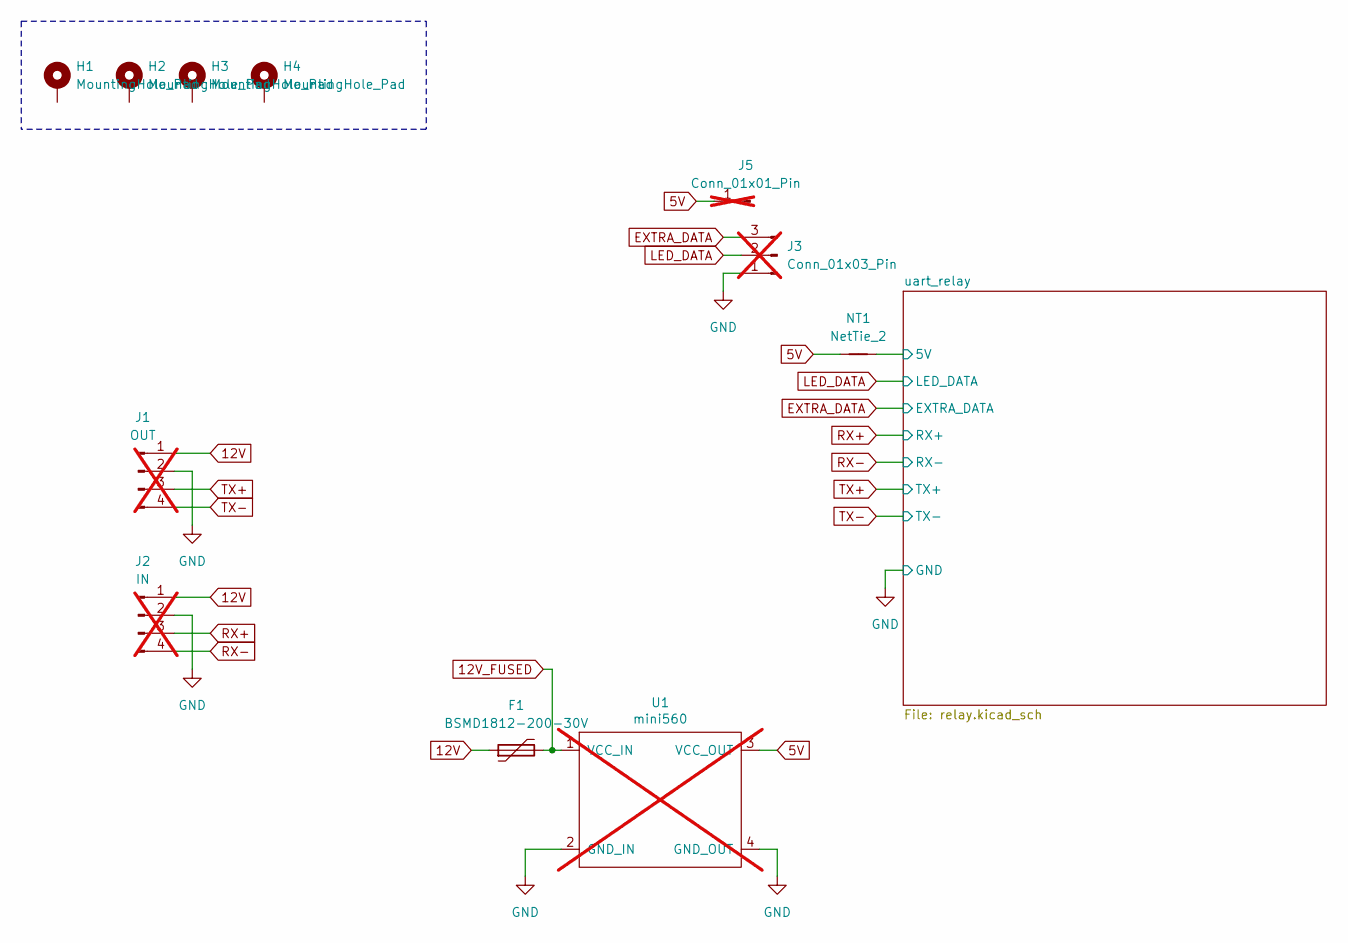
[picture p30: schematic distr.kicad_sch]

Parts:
F1: BSMD1812-200-30V; Fuse_1812_4532Metric; LCSC C960026
H1, H2, H3, H4: MountingHole_Pad; MountingHole_3mm_Pad_nocourtyard
J1: OUT; Molex_Micro-Fit_3.0_43650-0400_1x04_P3.00mm_Horizontal_silk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; not fitted
J2: IN; in_header; not fitted
J3: Conn_01x03_Pin; led_header_no_vcc; not fitted
J5: Conn_01x01_Pin; 5v_header; not fitted
NT1: NetTie_2; NetTie-2_SMD_Pad0.3mm
U1: mini560; mini560_minimal_silk_carveout; not fitted

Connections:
5V: J5.1, NT1.1, U1.3 (VCC_OUT)
12V: F1.1, J1.1, J2.1
12V_FUSED: F1.2, U1.1 (VCC_IN)
/uart_relay/5V: NT1.2; also elsewhere on the board
EXTRA_DATA: J3.3; also elsewhere on the board
GND: J1.2, J2.2, J3.1, U1.2 (GND_IN), U1.4 (GND_OUT); also elsewhere on the board
LED_DATA: J3.2; also elsewhere on the board
RX+: J2.3; also elsewhere on the board
RX-: J2.4; also elsewhere on the board
TX+: J1.3; also elsewhere on the board
TX-: J1.4; also elsewhere on the board

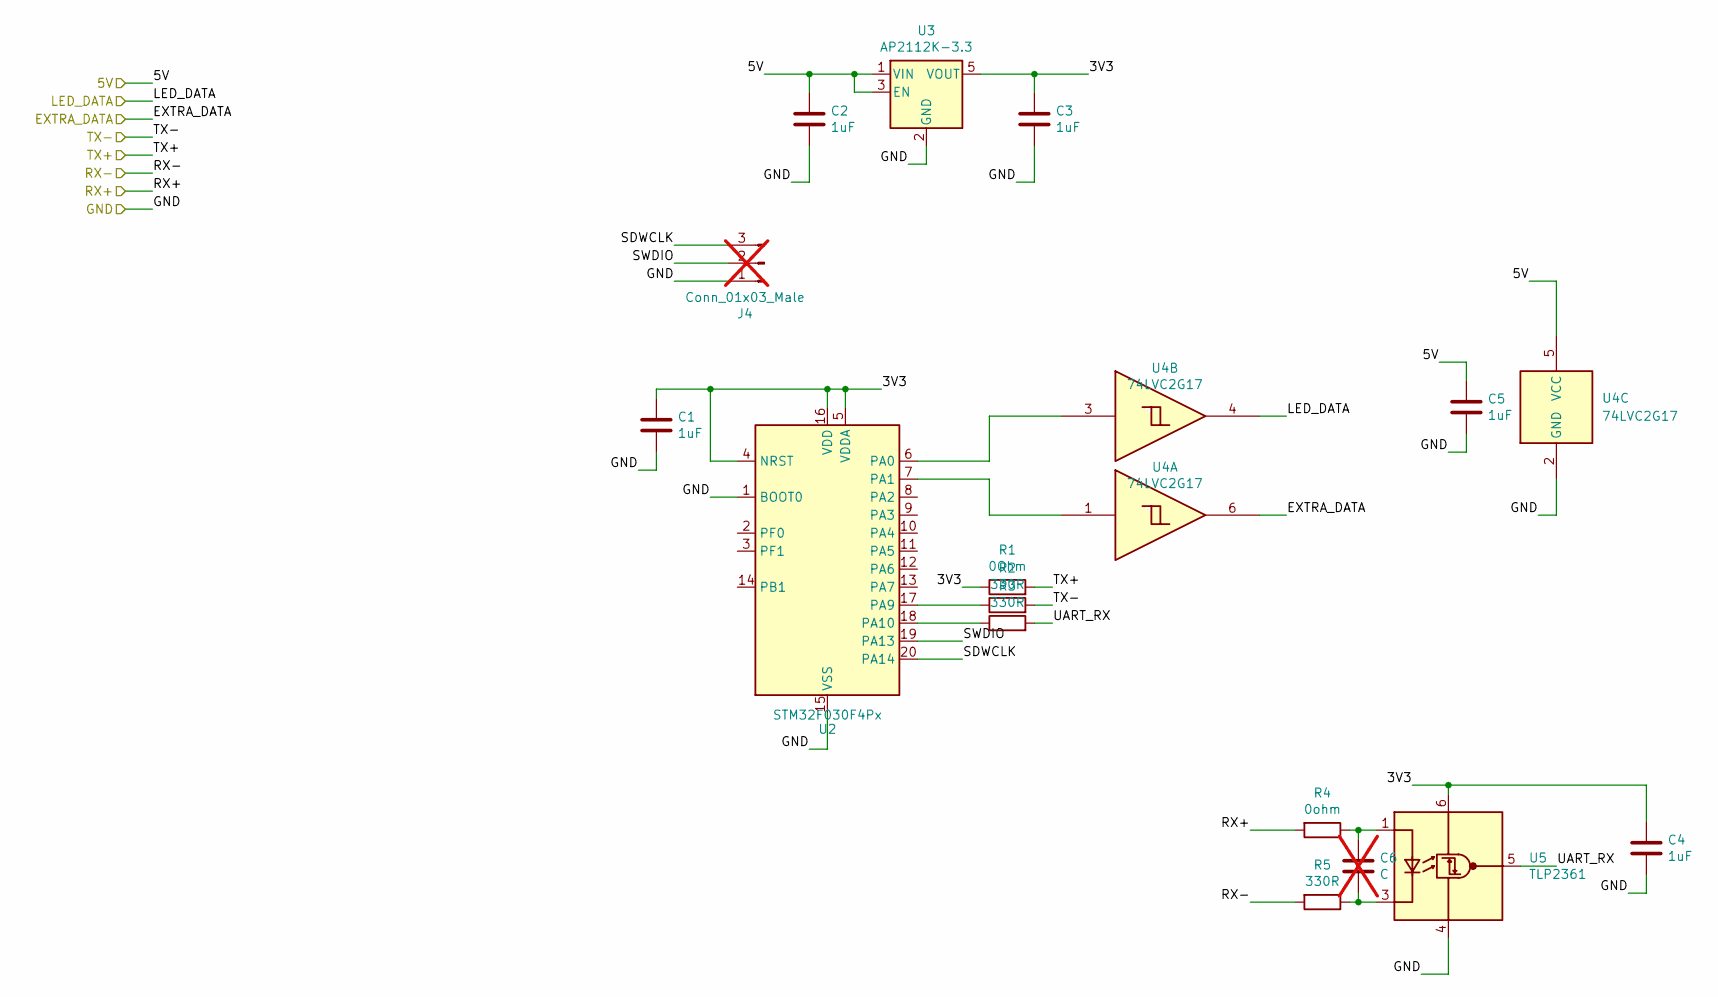
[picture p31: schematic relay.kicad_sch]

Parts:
C1, C2, C3, C4, C5: 1uF; C_0603_1608Metric; LCSC C15849
C6: C; C_0603_1608Metric; LCSC C15849; not fitted
J4: Conn_01x03_Male; SWD Header; not fitted
R1: 0Ohm; R_0603_1608Metric; LCSC C21189
R2, R3, R5: 330R; R_0603_1608Metric; LCSC C23138
R4: 0ohm; R_0603_1608Metric; LCSC C21189
U2: STM32F030F4Px; TSSOP-20_4.4x6.5mm_P0.65mm; LCSC C89040
U3: AP2112K-3.3; SOT-23-5; LCSC C51118
U4: 74LVC2G17; SOT-23-6_Handsoldering; LCSC C10429
U5: TLP2361; SO-5_4.4x3.6mm_P1.27mm; LCSC C107626

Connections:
/uart_relay/3V3: C1.1, C3.1, C4.1, R1.1, U2.4 (NRST), U2.5 (VDDA), U2.16 (VDD), U3.5 (VOUT), U5.6 (VDD)
/uart_relay/5V: C2.1, C5.1, U3.1 (VIN), U3.3 (EN), U4.5 (VCC); also elsewhere on the board
/uart_relay/SDWCLK: J4.3, U2.20 (PA14)
/uart_relay/SWDIO: J4.2, U2.19 (PA13)
/uart_relay/UART_RX: R3.2, U5.5 (VO)
EXTRA_DATA: U4.6; also elsewhere on the board
GND: C1.2, C2.2, C3.2, C4.2, C5.2, J4.1, U2.1 (BOOT0), U2.15 (VSS), U3.2 (GND), U4.2 (GND), U5.4 (GND); also elsewhere on the board
LED_DATA: U4.4; also elsewhere on the board
unnamed: U2.6 (PA0), U4.3
unnamed: U2.7 (PA1), U4.1
unnamed: R2.1, U2.17 (PA9)
unnamed: R3.1, U2.18 (PA10)
unnamed: C6.1, R4.1, U5.1 (A)
unnamed: C6.2, R5.1, U5.3 (K)
RX+: R4.2; also elsewhere on the board
RX-: R5.2; also elsewhere on the board
TX+: R1.2; also elsewhere on the board
TX-: R2.2; also elsewhere on the board

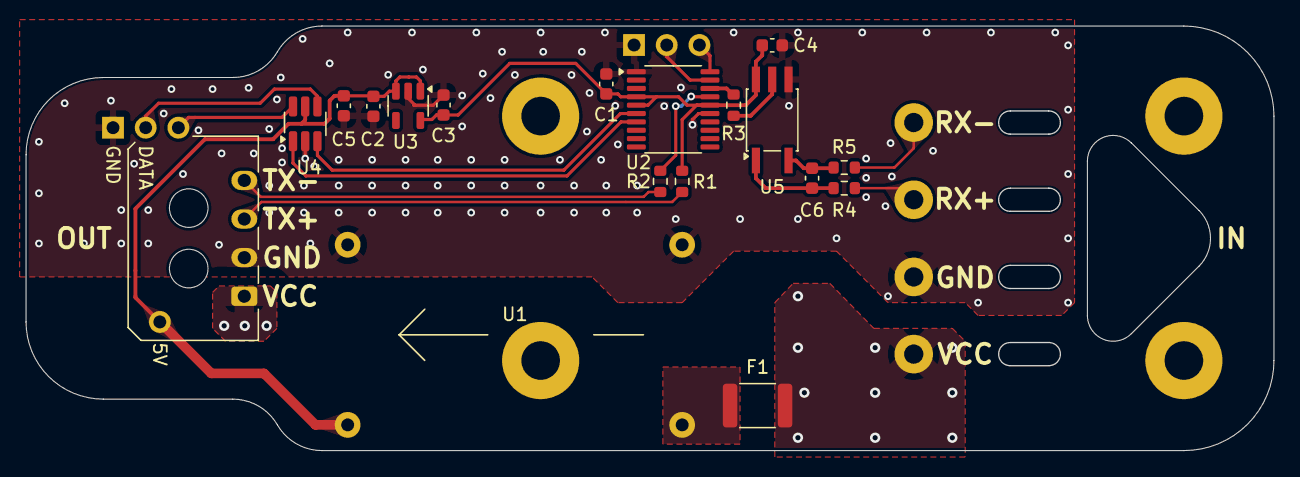
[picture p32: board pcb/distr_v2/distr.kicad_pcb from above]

Board: 2 copper layers, 97.0 x 33.0 mm, 27 parts (1 on the bottom side), 21 nets.

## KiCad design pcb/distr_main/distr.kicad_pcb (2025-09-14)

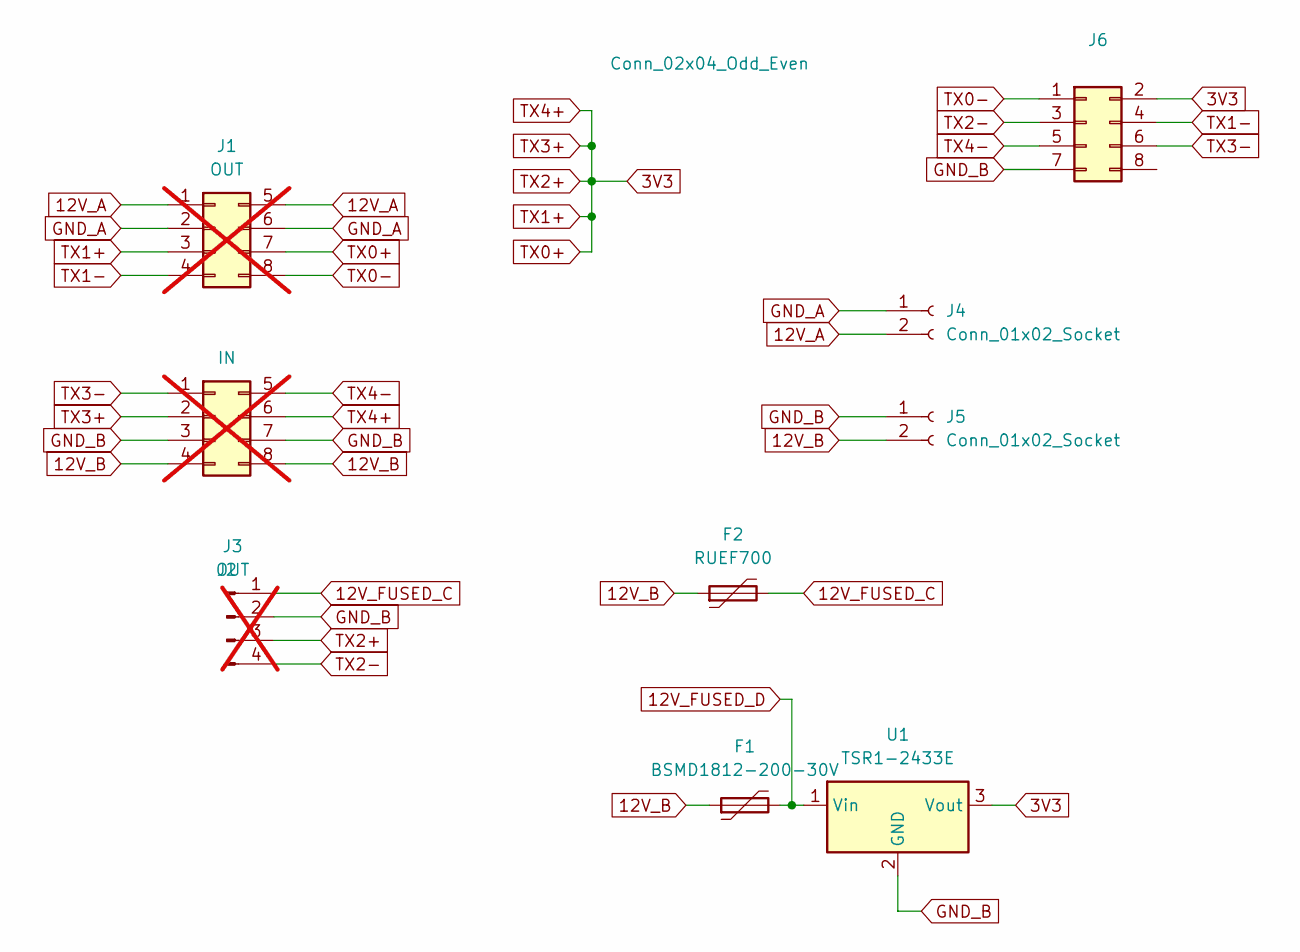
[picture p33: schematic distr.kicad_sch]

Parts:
F1: BSMD1812-200-30V; Fuse_1812_4532Metric; LCSC C960026
F2: RUEF700; Fuse_Littlefuse_RUEF
J1: OUT; Molex_Micro-Fit_3.0_43045-0800_2x04_P3.00mm_Horizontal; not fitted
J2: IN; Molex_Micro-Fit_3.0_43045-0800_2x04_P3.00mm_Horizontal; not fitted
J3: OUT; Molex_Micro-Fit_3.0_43650-0400_1x04_P3.00mm_Horizontal_silk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; not fitted
J4, J5: Conn_01x02_Socket; AMASS_XT60-F_1x02_P7.20mm_Vertical
J6: Conn_02x04_Odd_Even; PinSocket_2x04_P2.54mm_Vertical
U1: TSR1-2433E; Converter_DCDC_TRACO_TSR1-xxxxE_THT

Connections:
3V3: J1.3, J1.7, J2.2, J2.6, J3.3, J6.2, U1.3 (Vout)
12V_A: J1.1, J1.5, J4.2
12V_B: F1.1, F2.1, J2.4, J2.8, J5.2
12V_FUSED_C: F2.2, J3.1
12V_FUSED_D: F1.2, U1.1 (Vin)
GND_A: J1.2, J1.6, J4.1
GND_B: J2.3, J2.7, J3.2, J5.1, J6.7, U1.2 (GND)
TX0-: J1.8, J6.1
TX1-: J1.4, J6.4
TX2-: J3.4, J6.3
TX3-: J2.1, J6.6
TX4-: J2.5, J6.5

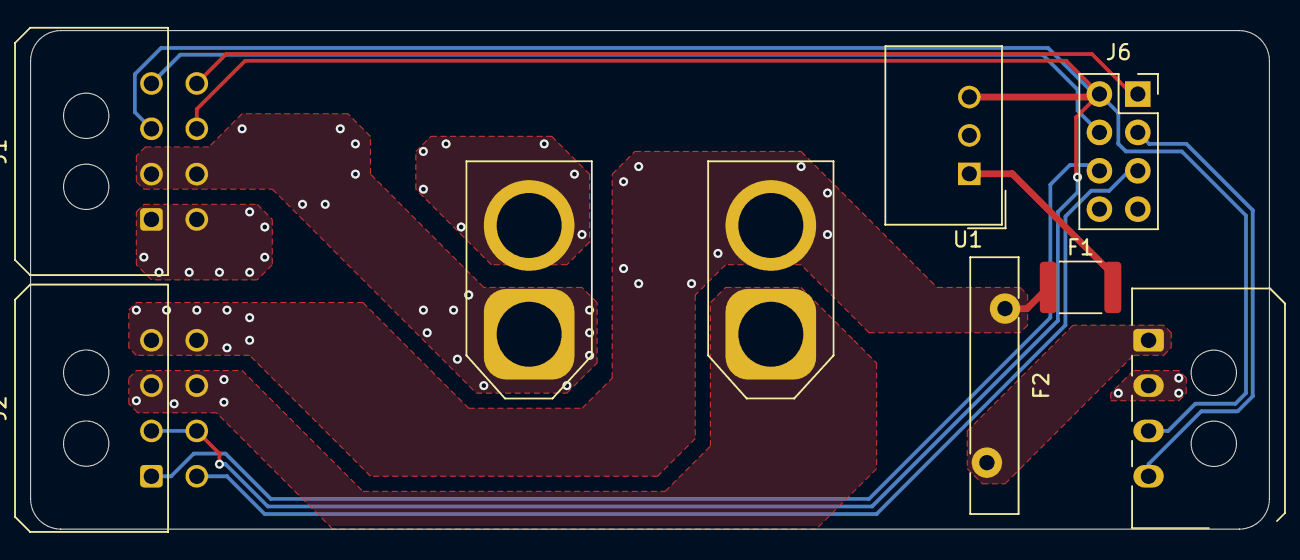
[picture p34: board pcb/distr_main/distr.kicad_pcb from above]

Board: 4 copper layers, 82.0 x 33.0 mm, 9 parts (0 on the bottom side), 12 nets.

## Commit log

2023-12-16 move data into separate repo
    [led.scad, wiring.scad, yjoint.kicad_pcb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]
2023-12-17 add info about driver board
2023-12-17 Laser cut desciption
2023-12-17 add driver picture
2023-12-17 add led location calculations
2023-12-17 add led strip spacing detail
2024-01-31 move pcb files
    [yjoint.kicad_pcb, yjoint.sch]
2024-01-31 add (untested) flexpcb
    [yjoint.kicad_pcb, yjoint.sch]
2024-02-01 reduce number of holes
    [yjoint.kicad_pcb]
2024-03-05 add strip numbering & top side annotation
    [wiring.scad]
2024-03-05 add reference to driver board v2
2024-04-18 power dist pcb for bigger sphere
    [distr.kicad_pcb, distr.sch]
2024-04-20 move laser cut files
    [led.scad]
2024-05-31 add opto distribution board
    [distr.kicad_pcb, distr.sch, panel.kicad_pcb]
2024-12-04 new hanger
    [hanger_v2.scad, hanger_v2.stl]
2025-01-01 add big sphere assembly documentation
2025-01-02 add assambly toold
    [assembly_tool_big.scad, assembly_tool_big.stl]
2025-01-03 add assembly tool
    [assembly_tool_big.scad, assembly_tool_big.stl]
2025-01-07 kicad 8
    [distr.kicad_pcb, distr.kicad_sch]
2025-04-24 add tool to align connectors for the big sphere
    [insert.scad, insert.stl]
2025-08-30 v2 segment pcb
    [bomfile_jlc.csv, distr.kicad_pcb, posfile_jlc.csv]
2025-08-30 modified hanger for the small ball
    [hanger_v2.scad]
2025-09-14 add PCBs with fuses, port to kicad 9
    [distr.kicad_pcb, distr.kicad_sch, distr.sch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]
2025-09-14 git ignore pcb backups
2025-09-14 add gerbers
2025-09-14 add cut files for a small tetrahedral sphere
    [tri.scad]
2025-09-14 add unfinished design for case padding
2025-09-14 make PCBA file generation optional
2025-09-18 re-label segments in assembly manual
2025-09-26 add wire guide model
    [big.scad, big_solid.scad, wire_guide_big.scad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]
2025-09-26 laser cut drawing for bottom plate with xt60 cutout
2025-09-26 update assembly manual
2025-10-01 add power connector stiffner cad files
    [power_insert.scad, power_insert.stl]
2025-10-01 add missing connector in schematic
2025-10-01 add missing connector to manual
2025-10-04 add [dis]assembly tools for new design
    [assembly_tool.scad, assembly_tool.stl, assembly_tool_old.scad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]
2026-01-13 add wire(-connection) clamp model
    [clamp.scad, clamp.stl]
